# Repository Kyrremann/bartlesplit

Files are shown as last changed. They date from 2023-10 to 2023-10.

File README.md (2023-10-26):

# Bartlesplit

> Bartleby is a baby Rat Creature adopted by Fone Bone and Smiley.

Bartlesplit is based on [Cheapino](https://github.com/tompi/cheapino) by Tompi.
The original idea was to build a Cheapino with hot swaps, but it evolved into something more!

At the same time I was working on Bartlesplit, a friend of mine suggested that we try to make a splithub, letting us avoid having the Pro Micro directly on the board.
This is mostly a design choice, as it means you need to have a hub for each keyboard to avoid switching Pro Micros.
We have called the hub [The Japanese Connection](https://github.com/Kyrremann/the-japanese-connection) since it's relying on the Japanese duplex matrix.

One of the main feature of the board is the built-in tenting, so you don't need to make a case to get simple tenting.

## v1.0 built

The first version has been built, and except for the diodes on the right split needed to be flipped, everything works as expected!
Break off parts was easy to remove and then sand down the bits sticking out.
I haven't tried to break away the sixth column yet, and it will probably be a bit harder, as I only used one hole for the mouse bits.

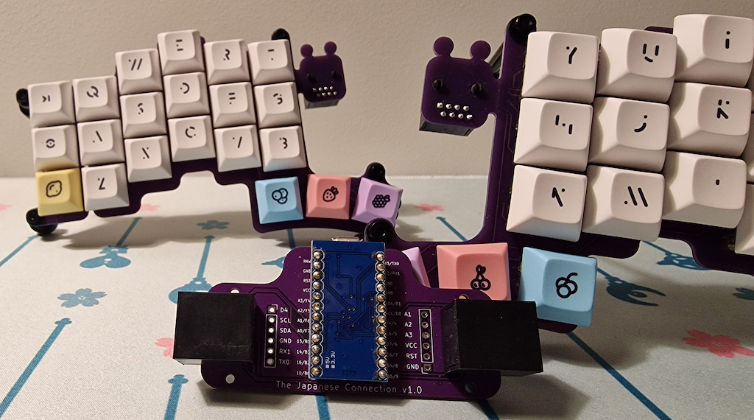
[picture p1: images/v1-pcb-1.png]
All three parts, the hub in the front, and then each split afterwards


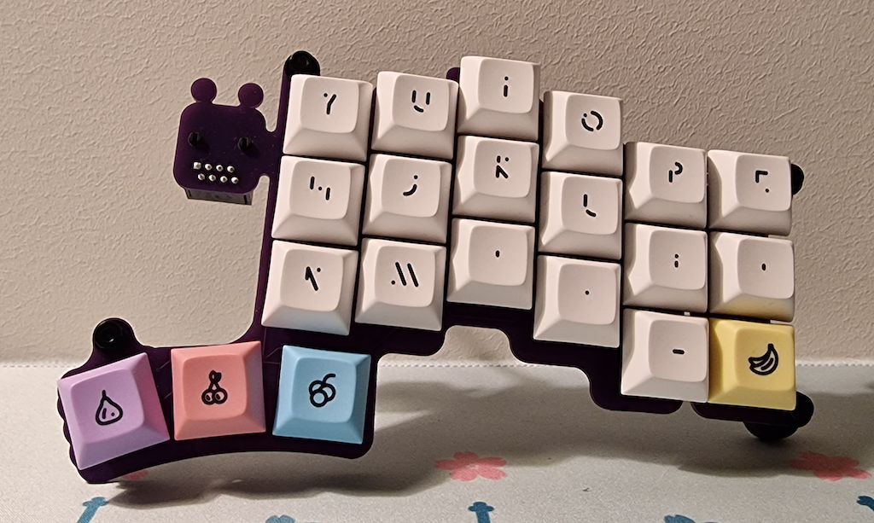
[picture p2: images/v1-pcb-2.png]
Showcasing the right hand with DSA Milkshake keycaps


Another image showing the three parts

## Render

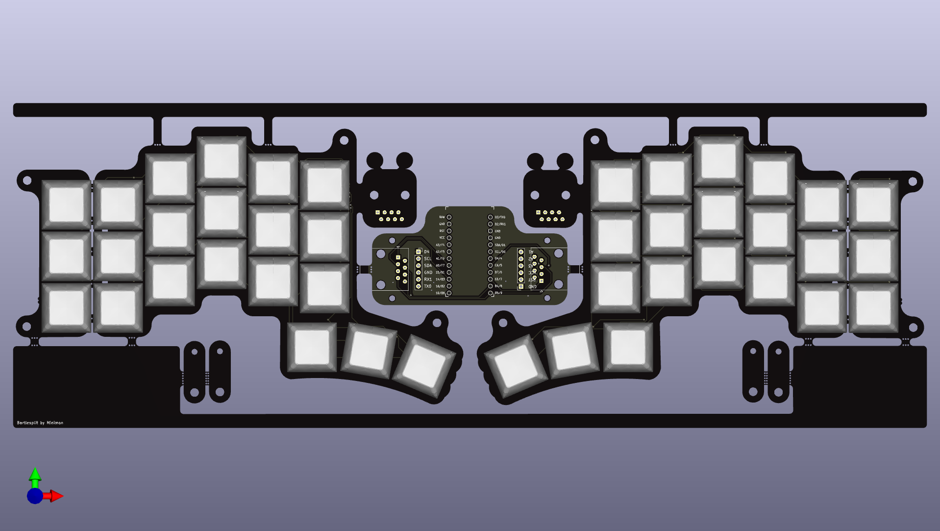
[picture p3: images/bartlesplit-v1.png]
A render of the split board


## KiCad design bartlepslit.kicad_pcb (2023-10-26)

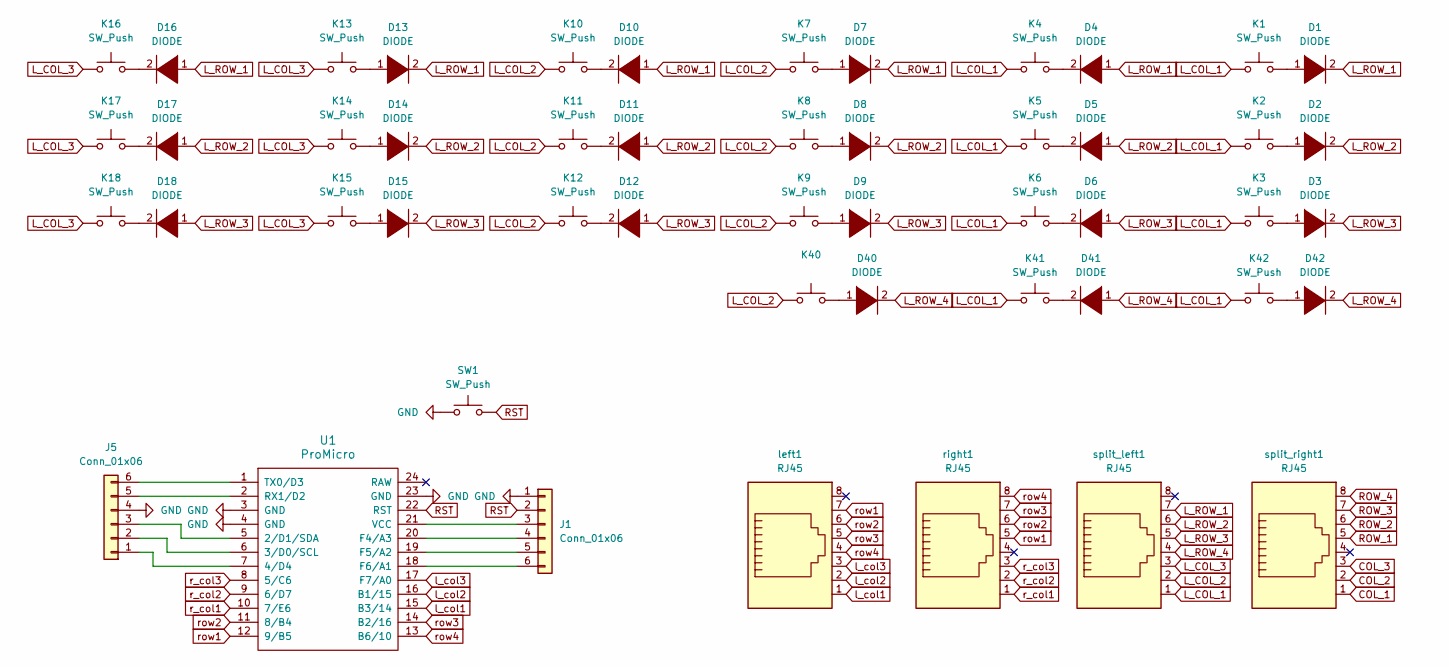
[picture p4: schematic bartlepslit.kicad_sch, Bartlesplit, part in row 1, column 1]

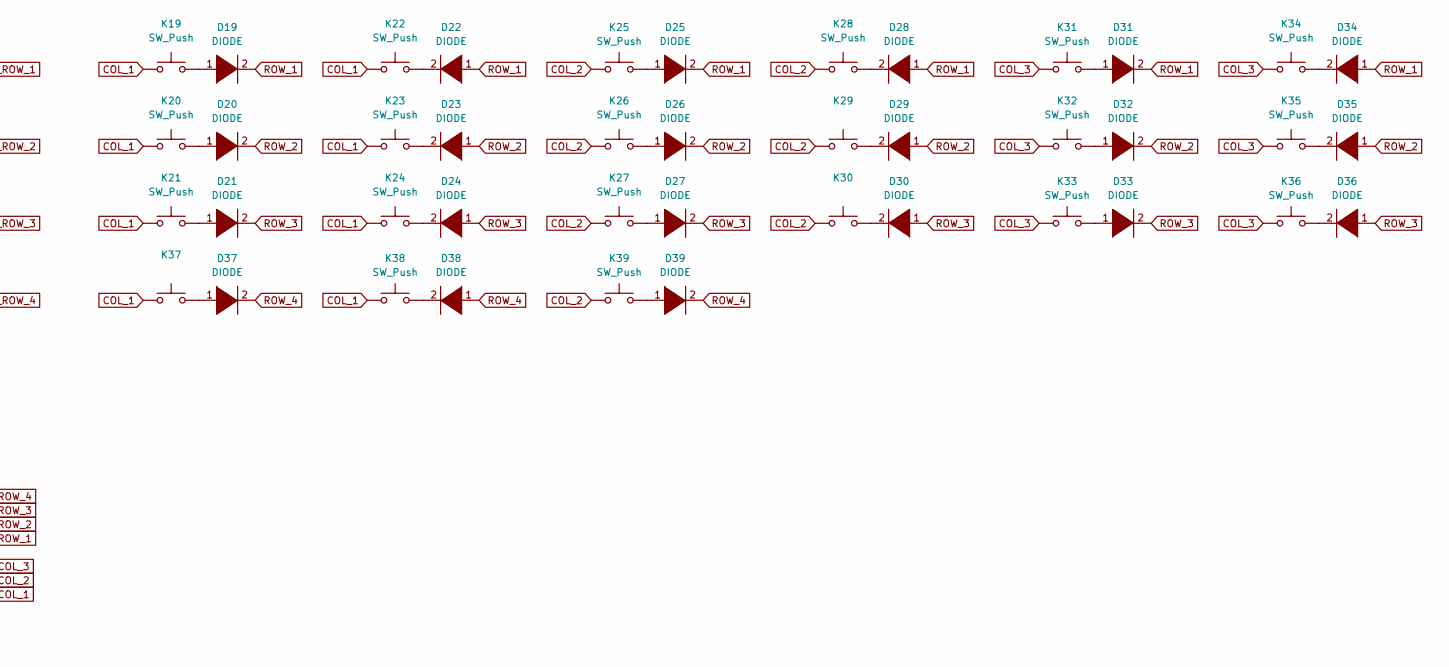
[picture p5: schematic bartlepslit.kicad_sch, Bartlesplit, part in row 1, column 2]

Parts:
D1, D2, D3, D4, D5, D6, D7, D8, D9, D10, D11, D12, D13, D14, D15, D16, D17, D18, D19, D20, D21, D22, D23, D24, D25, D26, D27, D28, D29, D30, D31, D32, D33, D34, D35, D36, D37, D38, D39, D40, D41, D42: DIODE; D_SOD-123
J1, J5: Conn_01x06; PinSocket_1x06_P2.54mm_Vertical
K1, K2, K3, K4, K5, K6, K7, K8, K9, K10, K11, K12, K13, K14, K15, K16, K17, K18, K19, K20, K21, K22, K23, K24, K25, K26, K27, K28, K29, K30, K31, K32, K33, K34, K35, K36, K37, K38, K39, K40, K41, K42: SW_Push; SW_Hotswap_Kailh_MX_1.00u
SW1: SW_Push; SW_Tactile_SPST_NO_Straight_CK_PTS636Sx25SMTRLFS
U1: ProMicro; ProMicro_v3.5
left1: RJ45; RJ45_Amphenol_54602-x08_Horizontal
right1: RJ45; RJ45_Amphenol_54602-x08_Horizontal
split_left1: RJ45; RJ45_Amphenol_54602-x08_Horizontal
split_right1: RJ45; RJ45_Amphenol_54602-x08_Horizontal

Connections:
COL_1: K19.1, K20.1, K21.1, K22.1, K23.1, K24.1, K37.1, K38.1, split_right1.1
COL_2: K25.1, K26.1, K27.1, K28.1, K29.1, K30.1, K39.1, split_right1.2
COL_3: K31.1, K32.1, K33.1, K34.1, K35.1, K36.1, split_right1.3
GND: SW1.1, U1.3 (GND), U1.4 (GND), U1.23 (GND); also elsewhere on the board
L_COL_1: K1.1, K2.1, K3.1, K4.1, K5.1, K6.1, K41.1, K42.1, split_left1.1
L_COL_2: K7.1, K8.1, K9.1, K10.1, K11.1, K12.1, K40.1, split_left1.2
L_COL_3: K13.1, K14.1, K15.1, K16.1, K17.1, K18.1, split_left1.3
L_ROW_1: D1.2 (A), D4.1 (K), D7.2 (A), D10.1 (K), D13.2 (A), D16.1 (K), split_left1.7
L_ROW_2: D2.2 (A), D5.1 (K), D8.2 (A), D11.1 (K), D14.2 (A), D17.1 (K), split_left1.6
L_ROW_3: D3.2 (A), D6.1 (K), D9.2 (A), D12.1 (K), D15.2 (A), D18.1 (K), split_left1.5
L_ROW_4: D40.2 (A), D41.1 (K), D42.2 (A), split_left1.4
unnamed: D1.1 (K), K1.2
unnamed: D2.1 (K), K2.2
unnamed: D3.1 (K), K3.2
unnamed: D4.2 (A), K4.2
unnamed: D5.2 (A), K5.2
unnamed: D6.2 (A), K6.2
unnamed: D7.1 (K), K7.2
unnamed: D8.1 (K), K8.2
unnamed: D9.1 (K), K9.2
unnamed: D10.2 (A), K10.2
unnamed: D11.2 (A), K11.2
unnamed: D12.2 (A), K12.2
unnamed: D13.1 (K), K13.2
unnamed: D14.1 (K), K14.2
unnamed: D15.1 (K), K15.2
unnamed: D16.2 (A), K16.2
unnamed: D17.2 (A), K17.2
unnamed: D18.2 (A), K18.2
unnamed: D19.1 (K), K19.2
unnamed: D20.1 (K), K20.2
unnamed: D21.1 (K), K21.2
unnamed: D22.2 (A), K22.2
unnamed: D23.2 (A), K23.2
unnamed: D24.2 (A), K24.2
unnamed: D25.1 (K), K25.2
unnamed: D26.1 (K), K26.2
unnamed: D27.1 (K), K27.2
unnamed: D28.2 (A), K28.2
unnamed: D29.2 (A), K29.2
unnamed: D30.2 (A), K30.2
unnamed: D31.1 (K), K31.2
unnamed: D32.1 (K), K32.2
unnamed: D33.1 (K), K33.2
unnamed: D34.2 (A), K34.2
unnamed: D35.2 (A), K35.2
unnamed: D36.2 (A), K36.2
unnamed: D37.1 (K), K37.2
unnamed: D38.2 (A), K38.2
unnamed: D39.1 (K), K39.2
unnamed: D40.1 (K), K40.2
unnamed: D41.2 (A), K41.2
unnamed: D42.1 (K), K42.2
unnamed 53: U1.5 (2/D1/SDA); also elsewhere on the board
unnamed 54: U1.6 (3/D0/SCL); also elsewhere on the board
unnamed 55: U1.7 (4/D4); also elsewhere on the board
unnamed 56: U1.20 (F4/A3); also elsewhere on the board
unnamed 57: U1.19 (F5/A2); also elsewhere on the board
unnamed 58: U1.18 (F6/A1); also elsewhere on the board
unnamed 59: U1.2 (RX1/D2); also elsewhere on the board
unnamed 60: U1.1 (TX0/D3); also elsewhere on the board
unnamed 61: U1.21 (VCC); also elsewhere on the board
ROW_1: D19.2 (A), D22.1 (K), D25.2 (A), D28.1 (K), D31.2 (A), D34.1 (K), split_right1.5
ROW_2: D20.2 (A), D23.1 (K), D26.2 (A), D29.1 (K), D32.2 (A), D35.1 (K), split_right1.6
ROW_3: D21.2 (A), D24.1 (K), D27.2 (A), D30.1 (K), D33.2 (A), D36.1 (K), split_right1.7
ROW_4: D37.2 (A), D38.1 (K), D39.2 (A), split_right1.8
RST: SW1.2, U1.22 (RST); also elsewhere on the board
l_col1: U1.15 (B3/14); also elsewhere on the board
l_col2: U1.16 (B1/15); also elsewhere on the board
l_col3: U1.17 (F7/A0); also elsewhere on the board
r_col1: U1.10 (7/E6); also elsewhere on the board
r_col2: U1.9 (6/D7); also elsewhere on the board
r_col3: U1.8 (5/C6); also elsewhere on the board
row1: U1.12 (9/B5); also elsewhere on the board
row2: U1.11 (8/B4); also elsewhere on the board
row3: U1.14 (B2/16); also elsewhere on the board
row4: U1.13 (B6/10); also elsewhere on the board

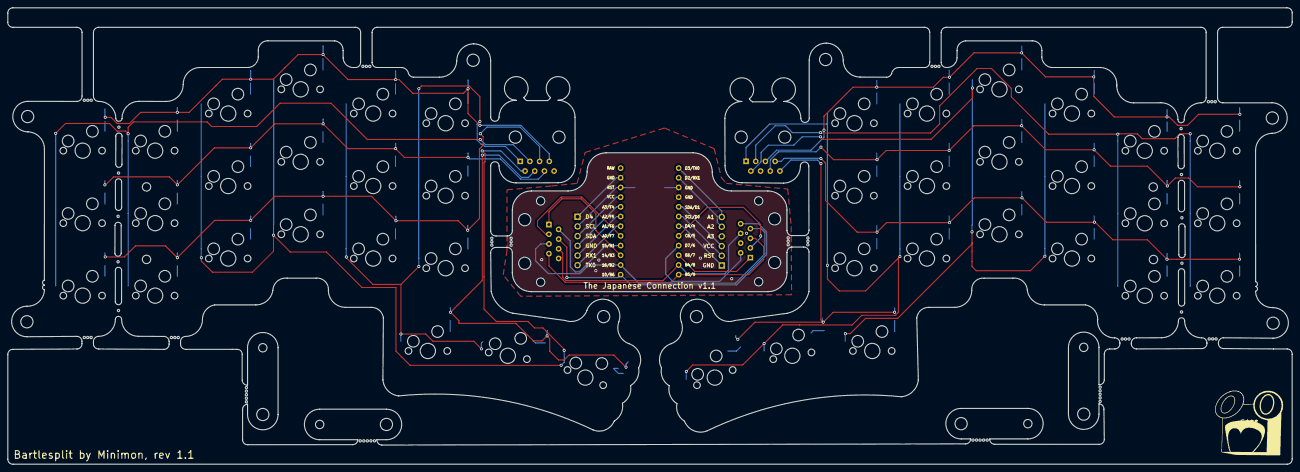
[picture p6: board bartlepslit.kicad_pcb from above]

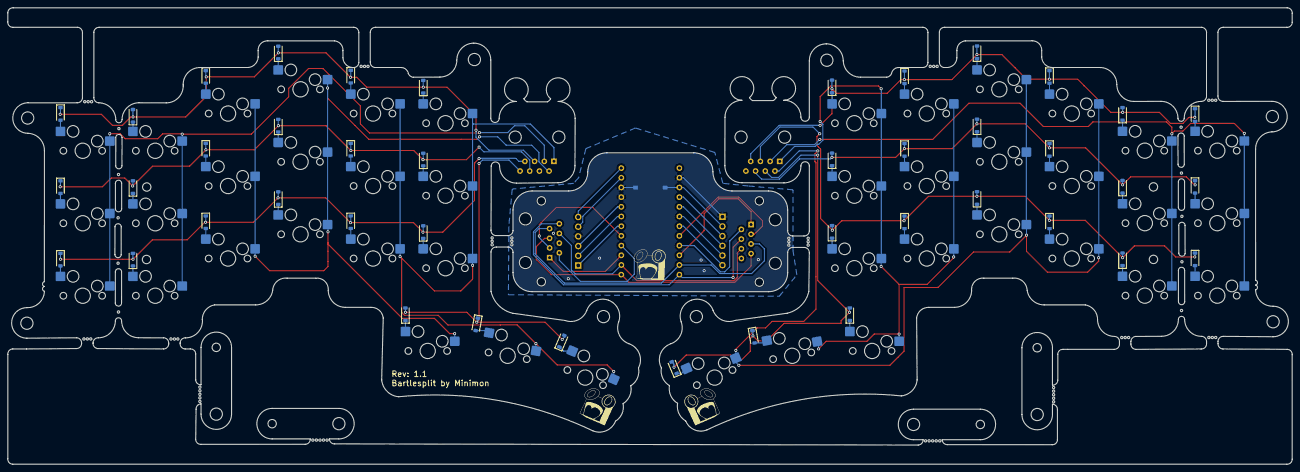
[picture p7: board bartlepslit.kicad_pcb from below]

Board: 2 copper layers, 336.7 x 119.6 mm, 92 parts (45 on the bottom side), 77 nets.

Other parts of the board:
tjc_j1, tjc_j2: Conn_01x06; PinSocket_1x06_P2.54mm_Vertical
tjc_left2: RJ45; RJ45_Amphenol_54602-x08_Horizontal
tjc_right2: RJ45; RJ45_Amphenol_54602-x08_Horizontal

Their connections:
GND: tjc_j1.4, tjc_j2.1; also elsewhere on the board
unnamed 53: tjc_j1.3; also elsewhere on the board
unnamed 54: tjc_j1.2; also elsewhere on the board
unnamed 55: tjc_j1.1; also elsewhere on the board
unnamed 56: tjc_j2.4; also elsewhere on the board
unnamed 57: tjc_j2.5; also elsewhere on the board
unnamed 58: tjc_j2.6; also elsewhere on the board
unnamed 59: tjc_j1.5; also elsewhere on the board
unnamed 60: tjc_j1.6; also elsewhere on the board
unnamed 61: tjc_j2.3; also elsewhere on the board
RST: tjc_j2.2; also elsewhere on the board
l_col1: tjc_left2.1; also elsewhere on the board
l_col2: tjc_left2.2; also elsewhere on the board
l_col3: tjc_left2.3; also elsewhere on the board
r_col1: tjc_right2.1; also elsewhere on the board
r_col2: tjc_right2.2; also elsewhere on the board
r_col3: tjc_right2.3; also elsewhere on the board
row1: tjc_left2.7, tjc_right2.5; also elsewhere on the board
row2: tjc_left2.6, tjc_right2.6; also elsewhere on the board
row3: tjc_left2.5, tjc_right2.7; also elsewhere on the board
row4: tjc_left2.4, tjc_right2.8; also elsewhere on the board

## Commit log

2023-10-19 feat: init commit
    [bartlepslit.kicad_pcb, bartlepslit.kicad_sch]
2023-10-26 feat: fixed orientation of diodes
    [bartlepslit.kicad_pcb, bartlepslit.kicad_sch]
2023-10-26 feat: removed unncessary silkprints
    [bartlepslit.kicad_pcb]
2023-10-26 feat: optimized break off parts
    [bartlepslit.kicad_pcb]
2023-10-26 feat: added missing reset switch
    [bartlepslit.kicad_pcb, bartlepslit.kicad_sch]
2023-10-26 feat: bump revison to v1.1
    [bartlepslit.kicad_pcb, bartlepslit.kicad_sch]
